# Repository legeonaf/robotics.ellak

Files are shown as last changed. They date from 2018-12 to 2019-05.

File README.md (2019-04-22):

# iHome
Συμμετοχή στο διαγωνισμό ρομποτικής της ellak σχολικού έτους 2018 - 19

**Γεωργία Λέων**  
2ο Γυμνάσιο Ναυπλίου

- [Τί είναι το Έξυπνο σπίτι](smarthome.md)
- [Εξαρτήματα - Τιμές](Εξαρτήματα/README.md)
- [Η Κατασκευή](Κατασκευή/README.md)
- [Ο Προγραμματισμός](Προγραμματισμός/README.md)

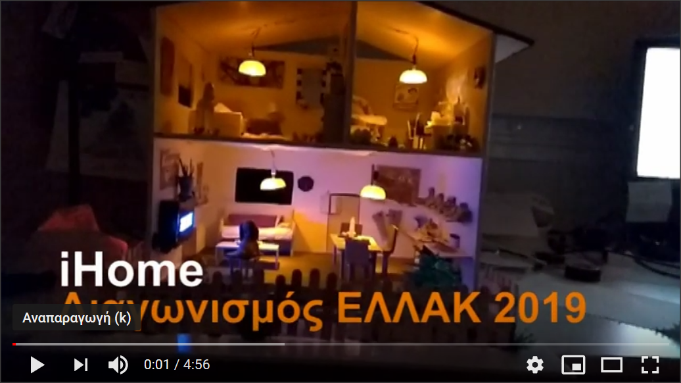
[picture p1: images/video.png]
(https://www.youtube.com/watch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)


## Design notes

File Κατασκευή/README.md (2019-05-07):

# Η κατασκευή

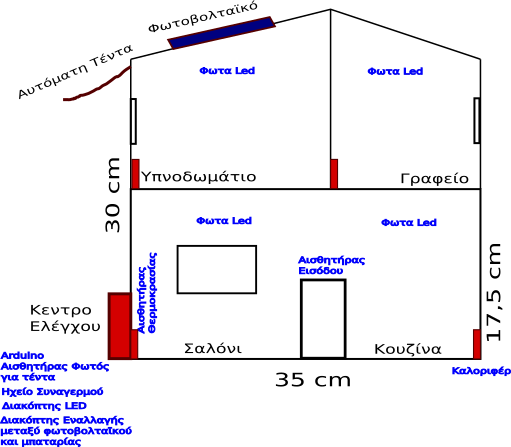
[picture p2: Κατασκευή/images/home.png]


## Συλλογή υλικών

Υλικά:
- Ξυλεία κόντρα πλακέ πάχους 0,5cm
- Ξυλόκολλα
- Ράβδοι κόλλας σιλικόνης, 4-5 ράβδοι
- Χρώματα και βερνίκια ξύλου της επιλογής μας
- Καρφιά και βίδες
- Στόκος ξύλου
- Μικροί μεντεσέδες, 2
- Καλώδια
- Μακετόχαρτο, 45cm*45cm
- Ξυλάκια παγωτού
- Ύφασμα

Για προαιρετικές διακοσμήσεις για το σπίτι και τον κήπο:
- Ξύλα Balsa,ύφασμα, χαρτί, βίδες (για έπιπλα)
- Πράσινο χαρτί γκοφρέ (για γρασίδι)
- Ακρυλικά χρώματα (για το μονοπάτι του κήπου)
- Έτοιμες φιγούρες, φυτά και μινιατούρες επίπλων/πραγμάτων
- Χάρτινα ποτήρια με σχέδια (για πίνακες)

Εργαλεία:
- Χάρακας
- Μέτρο
- Γυαλόχαρτα
- Σφυρί
- Τρυπανάκι
- Kατσαβίδι
- Μολύβι
- Πριόνι
- Χαρτοταινία
- Πιστόλι σιλικόνης

## Επεξεργασία ξυλείας

### Κοπή ξύλων
Μετράμε, σχεδιάζουμε και κόβουμε με το πριόνι τα ξύλα κόντρα πλακέ σε οκτώ παραλληλόγραμμα όπως φαίνοτναι στο σχήμα.
(Π):
- Π1 (πάτωμα κάτω) 35cm*25cm
- Π2 (πάτωμα πάνω) 35cm*25cm
- Π3 (τοίχος δεξιά) 30cm*25cm
- Π4 (τοίχος αριστερά) 30cm*25cm
- Π5 (τοίχος μέση) 17cm*26cm
- Π6 (σκεπή δεξιά) 20,5cm*25cm
- Π7 (σκεπή αριστερά) 26cm*25cm
- Π8 (τοίχος πίσω) 36cm*31cm

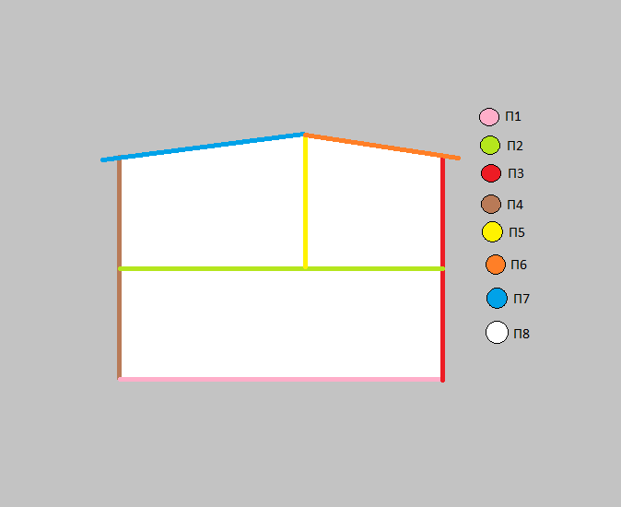
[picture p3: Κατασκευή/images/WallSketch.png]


### Κοπή παραθύρων
Για τα δύο πλαίνα παράθυρα παίρνουμε τα Π3 και Π4 και κόβουμε δύο παραλληλόγραμμες τρύπες για παράθυρα διαστάσεων
8cm(πλάτος)x6cm(ύψος) σε ύψος 21cm και με απόσταση απο τα άκρα 8cm απο την αριστερή άκρη του ξύλου και 9cm απο την δεξιά.
Για το πίσω παράθυρο παίρνουμε το Π8 και κόβουμε ένα παραλληλόγραμμο παράθυρο διαστάσεων 9cm(πλάτος)x5cm(ύψος) σε ύψος 8cm και με απόσταση απο τα άκρα 5,5cm απο την αριστερή άκρη και 21,5cm απο την δεξιά. Για την πόρτα παίρνουμε το ίδιο ξύλο και κάνουμε μια παραλληλόγραμμη τρύπα διαστάσεων 10cm(ύψος)x5cm(πλάτος) με απόσταση απο τα άκρα 20cm απο  την αριστερή άκρη και 11cm απο την δεξιά.

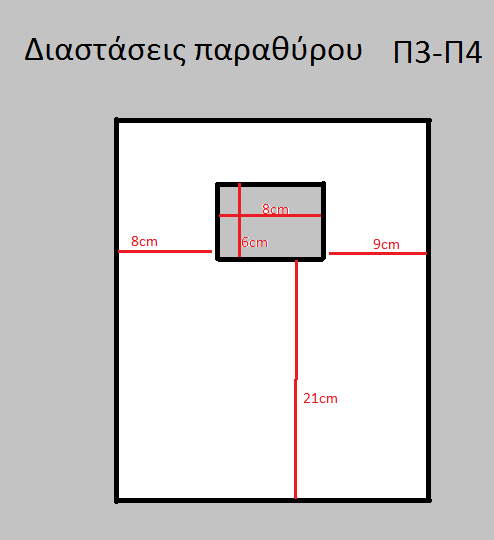
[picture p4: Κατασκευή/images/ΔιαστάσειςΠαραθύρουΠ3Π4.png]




### Στοκάρισμα παραθύρων και πόρτας
Για το στοκάρισμα χρησιμοποιούμε τον στόκο ξύλου και αλείφουμε τις εσωτερικές άκρες των παραθύρων και της πόρτας(κυρίως στος γωνίες) οσο χρειάζεται μεχρι να καλυφθούν τυχών εσοχές και γρατζουνιές που προκλήθηκαν κατα την κοπή. Αφόυ στεγνώσουν τρίβουμε όλα τα ξύλα με το γυαλόχαρτο στις άκρες και στην επιφάνεια καθώς και εκεί που στοκάραμε.



           

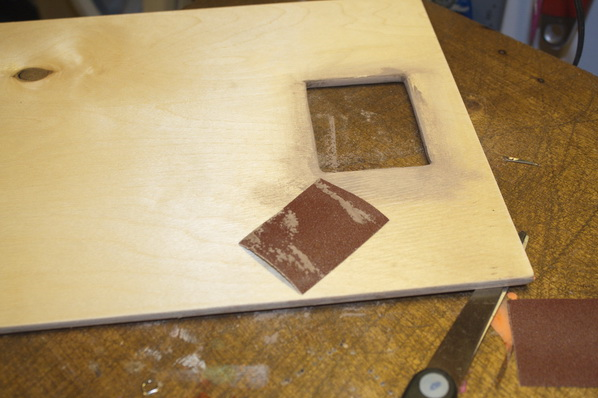
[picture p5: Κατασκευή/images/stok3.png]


## Συναρμολόγηση κομματιών
Για την συναρμολόγηση τρυπάμε τα ξύλα με το τρυπανάκι εκεί που θα βάλουμε τα καρφιά, τα κολλάμε και τα καρφώνουμε σύμφωνα με το σχήμα.



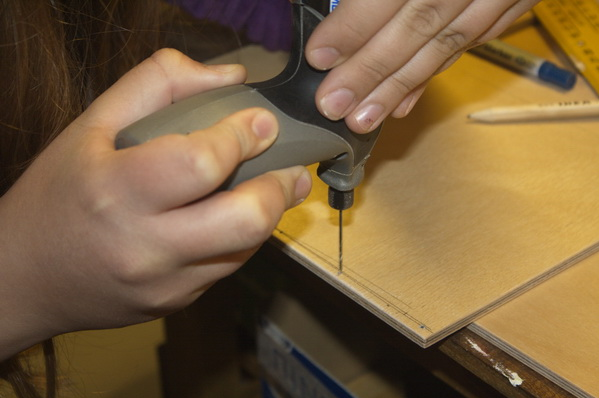
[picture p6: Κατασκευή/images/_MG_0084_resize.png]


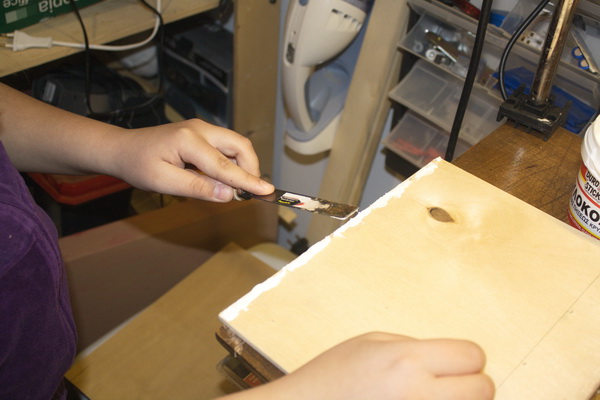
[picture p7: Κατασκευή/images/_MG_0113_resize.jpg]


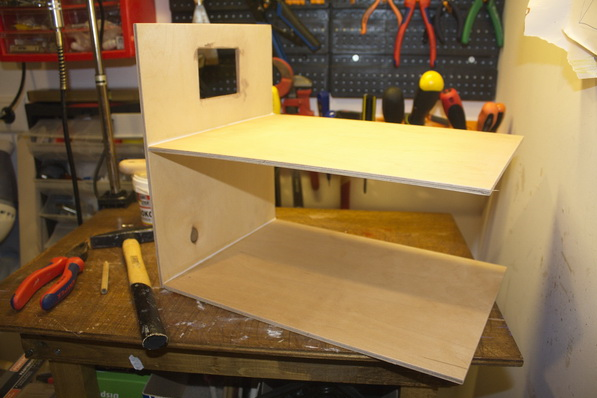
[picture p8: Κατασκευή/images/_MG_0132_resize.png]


## Βάψιμο
Σε αυτό το στάδιο βερνικώνουμε τα πατώματα και αφού στεγνώσουν βάφουμε τους εξωτερικούς και τους εσωτερικούς τοίχους του σπιτιού με χρώματα της επιλογής μας. Χρησιμοποιούμε χαρτοταινία για να μην λερώσουμε το πάτωμα.

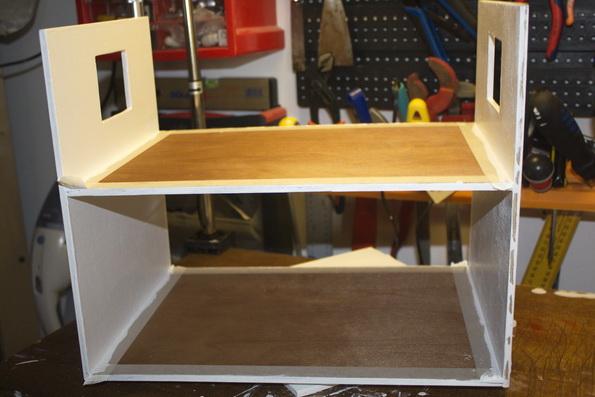
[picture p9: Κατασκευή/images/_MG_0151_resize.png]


## Η κατασκευή της πόρτας
Για την πόρτα θα χρειαστούμε ένα ορθογώνιο ελάχιστα μικρότερο απο την τρύπα στον τοίχο, 9,8cm(ύψος)x4,8cm(πλάτος),για να μπορεί να ανοίγει με τον συναγερμό τοποθετημένο. Βάφουμε την πόρτα με χρώμα της αρεσκείας μας και σε ύψος 5cm
βιδώνουμε μία μικρή βίδα για χερούλι (να μην βγεί απο την άλλη μεριά). Έπειτα με κοντές βίδες βιδώνουμε τoυς μεντεσέδες στην πόρτα και μετά στον τοίχο.

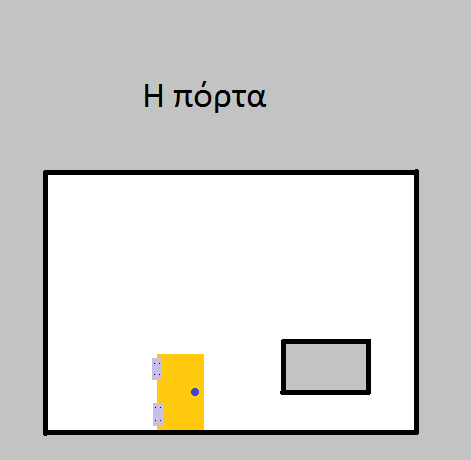
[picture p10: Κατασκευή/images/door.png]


## Η αυλή
Την αυλή την στήνουμε πάνω σε ένα κομμάτι μακετόχαρτο (Εικ.1). Η κατασκευή των φραχτών και της πόρτας γίνεται όπως υποδεικνύει το σκίτσο (Εικ.2+Εικ.3) και με διαστάσεις 11cm, 15cm και 7cm (Εικ.4). Έπειτα κολλάμε τους φράχτες (όχι την πόρτα) στο μακετόχαρτο με κόλλα σιλικόνης (εφόσον θέλετε να διακοσμήσετε τον κήπο κολλήστε και ζωγραφίστε το δάπεδό του πρίν την τοποθέτηση των φραχτών).

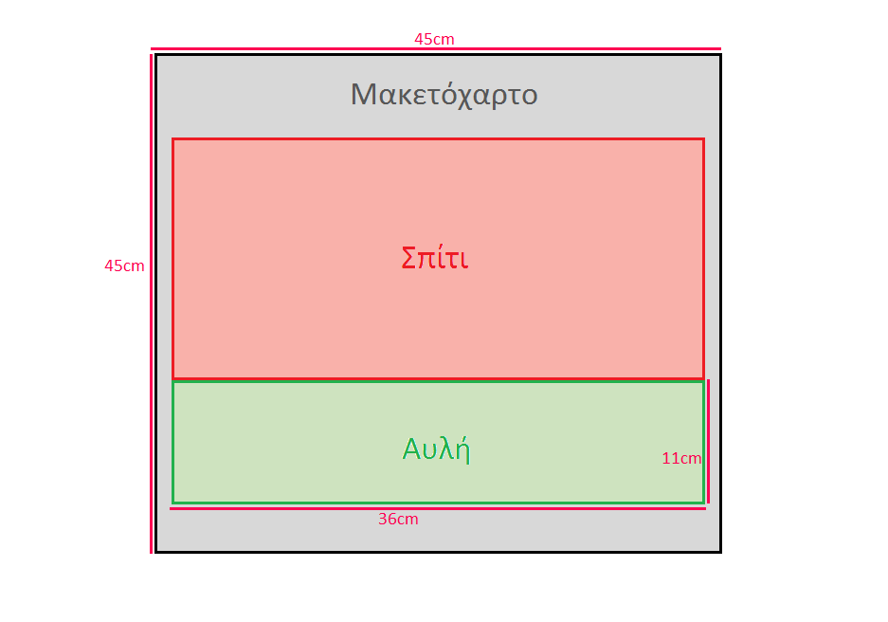
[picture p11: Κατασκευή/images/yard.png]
    
Εικ 1

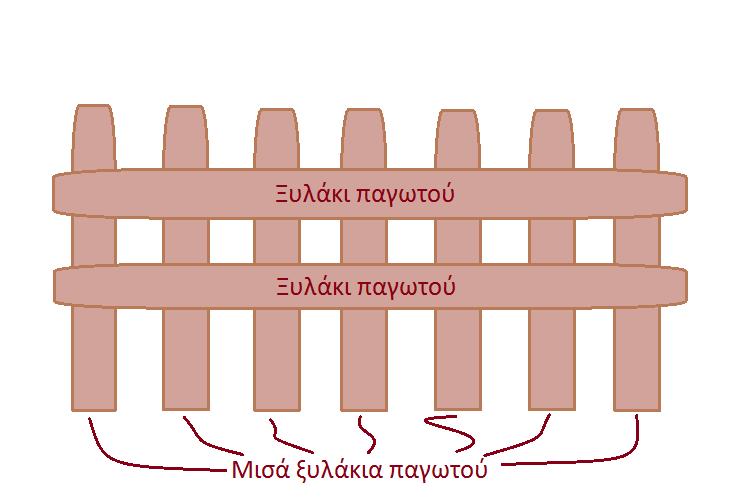
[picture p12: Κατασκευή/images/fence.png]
     
Εικ 2

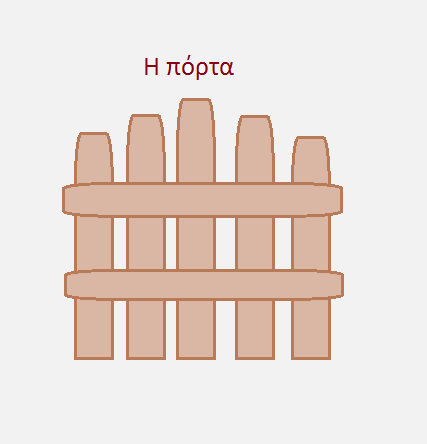
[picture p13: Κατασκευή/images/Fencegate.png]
   
Εικ 3

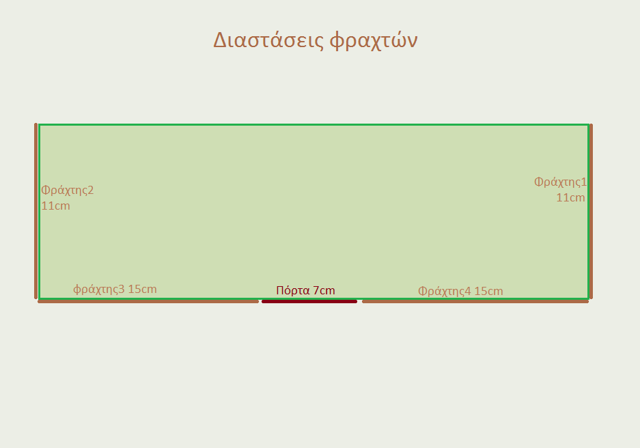
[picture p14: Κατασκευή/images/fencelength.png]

Εικ 4

## Η τέντα
Η τέντα αποτελείται απο τον σκελετό, τρία ξυλάκια για σουβλάκι (τα δύο 9cm και το μεσαίο 11cm) κολλημένα σε σχήμα Π με σιλικόνη, και το πανί (11cm x 11cm) του οποίου η μία άκρη είναι κολλημένη στο πάνω μέρος του παραθύρου και η απένατι άκρη στο μεσαίο ξυλάκι του σκελετού. Τα ξυλάκια στηρίζονται στον τοίχο απο δύο κλειστά γατζάκια που κλείνουν γύρω απο δύο μικρούς δακτυλίους που θα βιδώσουμε (ο ένας 1cm αριστερότερα απο το παράθυρο και ο άλλος 1cm δεξιότερα, και οι δύο σε ευθεία με την βάση του παραθύρου) ωστε να μπορεί να ανοιγοκλείνει.



## Καλωδίωση και τοποθέτηση εξαρτημάτων
###### Τώρα η μακέτα είναι έτοιμη να καλωδιωθεί:

#### Φώτα
Τα φώτα είναι 4 και τοποθετούνται 2 σε κάθε όροφο. Για τα πάνω φώτα βρίσκουμε την μέση του ταβανιού των δύο δωματίων.
Εκεί θα είναι οι άκρες των καλωδίων. Aρχίζοντας απο εκεί κολλάμε τις άκρες τους με σιλικόνη κάθετα και συνεχίζουμε να κολλάμε το καλώδιο ακολουθόντας κατεύθυνση προς το Arduino (D3-D4, GND).

#### Οθόνη
Η οθόνη θα τοποθετηθεί στον τοίχο Π4 δίπλα στο καλοριφέρ. Φτιάχνουμε ένα πλαίσιο απο μακετόχαρτο και την κολλάμε μέσα. Ανοίγουμε μια τρύπα στον τοίχο απο όπου θα βγαίνουν τα καλώδια της. Έπειτα την κολλάμε στον τοίχο με σιλικόνη. Τα καλώδια θα βγούν απο τον τοίχο και θα συνδεθούν στο Arduino (A4-A5, GND, 5v).

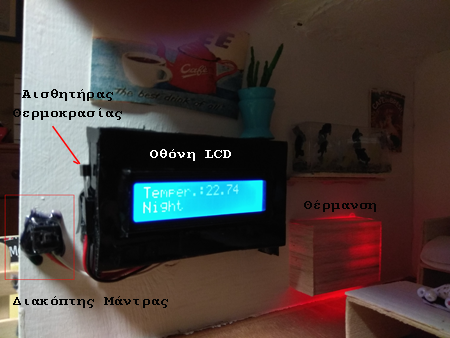
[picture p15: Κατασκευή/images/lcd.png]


Η οθόνη εμφανίζει συνεχώς την θερμοκρασία του χώρου στην πρώτη γραμμή ενώ στην δεύτερη ανάλογα με την ένδειξη του αισθητήρα φωτός εμφανίζει Day ή Night.

#### Θερμανση
Το καλοριφέρ είναι φτιαγμένο απο ένα λεπτό ξύλινο παραλληλόγραμμο ξύλο balsa χωρίς πάτο. Μέσα κολλάμε ένα κόκκινο LED φωτάκι μαζί με μια αντίσταση 220Ω σε σειρά με τον θερικό πόλο. Το καλοριφέρ θα τοποθετηθεί στον τοίχο Π4.  Κάνουμε μία τρύπα στον τοίχο, περνάμε απο μέσα τα καλώδια, τα συνδέουμε στο Arduino και  κολλάμε το καλοριφέρ με σιλικόνη στο Π4 (D13, GND). Μέσα από τον κώδικα έχει γίνει ρύθμιση να ανάβει το led (δηλαδή η θέρμανση) όταν η θερμοκρασία πέσει κάτω από 23 βαθμούς. Παράλληλα ακόμη και αν είναι μέρα η τέντα σηκώνεται ώστε να βοηθήσει ο ήλιος στη θέρμανση του σπιτιού.

#### Συναγερμός
Ο  συναγερμός θα τοποθετηθεί στην πόρτα όπως υποδεικνύει το σκίτσο με τα καλώδια να κατευθύνονται προς το Arduino (D9, GND).

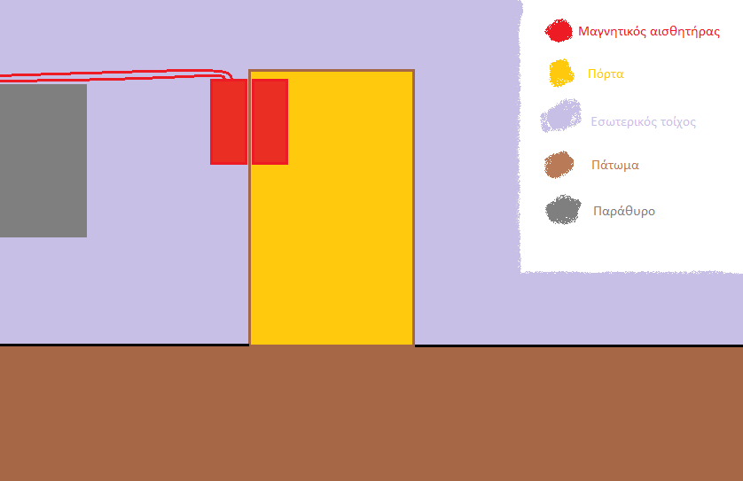
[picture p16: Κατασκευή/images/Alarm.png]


#### Κινητήρας τέντας
O κινητήρας της τέντας θα κολληθεί πλάγια στην αριστερή πλευρά του παραθύρου με τον βραχείωνα κολλημένο στο αριστερό ξυλάκι του σκελετού της. Τα καλώδια ακολουθούν κατεύθυνση προς το Arduino (D12, GND).


#### Κινητήρας αυλόπορτας
Ο κινητήρας της αυλόπορτας θα κολληθεί σε όρθια θέση στην αριστερή πλευρά του ανοίγματος για την πόρτα με τα καλώδια να κοιτάνε προς αυτό. Παίρνουμε τον βραχείωνα του κινητήρα και κολλάμε πάνω την πόρτα που έχουμε ετοιμάσει απο πρίν, προσέχοντας να υπάρχει περιθώριο ανάμεσσα στο δάπεδο και την πόρτα για να μπορεί να ανοιγοκλείνει. Έπειτα κάνουμε μία τρύπα στο μακετόχαρτο εκεί που είναι τα καλώδια του κινητήρα και τα περνάμε απο κάτω, για να μην φαίνονται, ακολουθώντας κατεύθυνση προς το Arduino (D11, GND, 5V).
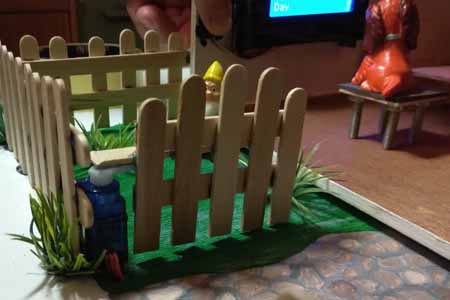
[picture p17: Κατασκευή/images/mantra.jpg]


#### Διακόπτης λειτουργίας & Διακόπτης φωτών
Ο διακόπτης λειτουργίας είναι τριών επιλογών. Στην θέση 1 τροφοδοτεί το Arduino απο μπαταρία 9 volt, στην θέση 2 τροφοδοτείται το Arduino απο τα φωτοβολταϊκά και στην θέση 0 είναι σβηστό.

Ο διακόπτης τοποθετείται στην θήκη του Arduino απο την εξωτερική πλευρά (D5, GND)


#### Διακόπτης αυλόπορτας
Ο διακόπτης της εξώπορτας θα τοποθετηθεί στο εσωτερικό του σπιτιού δίπλα στην τηλεόραση ωστε τα καλώδιά του να βγούν απο την τρύπα στον τοίχο και να ακολουθήσουν πορεία προς το Arduino (D6, GND).

#### Ηχείο
Το ηχείο τοποθετείται στο κουτί του Arduino (D8, GND)

#### Φωτοβολταικά
Τα φωτοβολταικά παράγουν 6v τάσης και είναι συνδεδεμένα παράλληλα προκειμένου να δίνουν επαρκή ένταση σε όλα τα εξαρτήματα του σπιτιού .

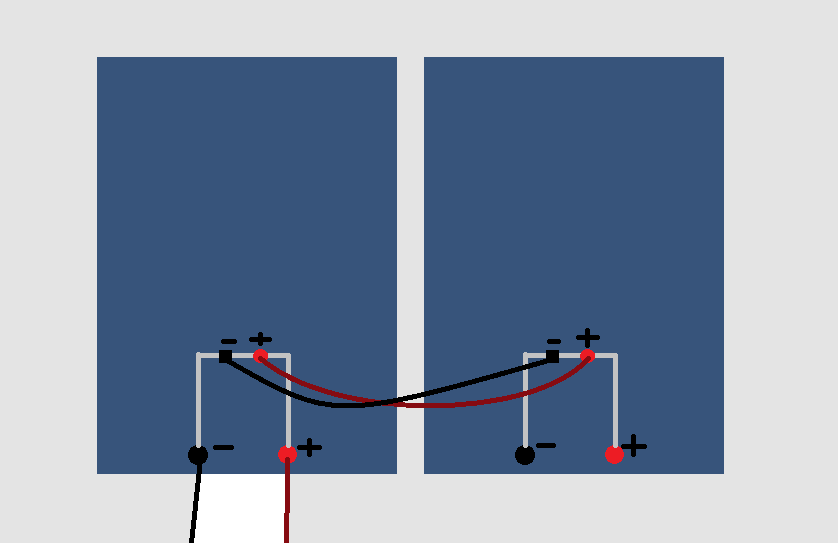
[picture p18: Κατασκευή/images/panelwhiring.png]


#### Αισθητήρας θερμοκρασίας
Ο αισθητήρας θερμοκρασίας τοποθετείται πάνω στο πλαίσιο της οθόνης με τα καλώδια να περνάνε μέσα απο το πλαίσιο, να βγαίνουν απο την τρύπα στον τοίχο και ναι κατευθύνονται προς το Arduino (Α1, GND, 5v)

#### Φωτοαντίσταση
Η φωτοαντίσταση τοποθετείται πάνω στο κουτί του Arduino κάτω απο τον κινητήρα της τέντας και συνδέεται με το Arduino (A2, GND, )

[Αρχική Σελίδα έργου](https://github.com/legeonaf/robotics.ellak)

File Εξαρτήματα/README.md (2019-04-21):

# Τα εξαρτήματα, τιμές και η χρήση τους

## Εξαρτήματα - Τιμές
A/A   | Περιγραφή   | Ποσότητα  | Τιμή / Τεμ. € | Σύνολο €
------| ------------|-----------|---------------|----------
1 | [LM35DZ LM35 TO-92 NSC TEMPERATURE SENSOR IC](https://www.ebay.com/itm/1PCS-LM35DZ-LM35-TO-92-NSC-TEMPERATURE-SENSOR-IC-Inductor-NEW/232397948189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) | 1 | 0.84 | 0.84
2 | [Αισθητήρας φωτός](https://www.ebay.com/itm/1-2-5-10-PCS-LM393-Optical-Photosensitive-Light-Sensor-Module-Arduino-Shield/302095762590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) | 1 | 0.65 | 0.65
3 | Αισθητήρας πόρτας (μαγνητική επαφή διακόπτης)| 1 | 1 | 1
4 | [Led για τα φώτα λευκά ή κίτρινα](https://grobotronics.com/led-diffused-5mm-white.html) | 4 | 0.2 | 0.8
5 | [Led για τα καλοριφέρ](https://grobotronics.com/led-diffused-5mm-elrd.html)  | 1 | 0.1 | 0.1
6 | [Κινητήρας σέρβο για την τέντα](https://grobotronics.com/servo-micro-1.5kg.cm-plastic-gears-feetech-fs90.html) | 1 | 4.90 | 4.90
7 | [Κινητήρας σέρβο για την μάντρα](https://grobotronics.com/servo-micro-1.5kg.cm-plastic-gears-feetech-fs90.html) | 1 | 4.90 | 4.90
8 | [Solar Panel 2W 136x110mm](https://grobotronics.com/solar-panel-2w-136x110mm.html)  | 2  |  5.90 |  11.80  |        
9 | [Ηχείο buzzer](https://grobotronics.com/buzzer-2-5v-30ma.html) | 1 | 0.65 | 0.65
10| [I2C 1602 Blue Backlight LCD Display Screen Module For Arduino](https://www.ebay.com/itm/IIC-I2C-1602-Blue-Backlight-LCD-Display-Module-For-Arduino/382822425595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)  | 1  | 3 | 3.53
11| [Arduino Nano compatible](https://grobotronics.com/nano-ft232-atmega328p-compatible-for-arduino-nano.html) | 1  | 9  |  9
12  | [Project Box 135x135x60mm](https://grobotronics.com/project-box-135x135x60mm-grey.html)   | 1   | 6.4  |  6.4
13| Αντιστάσεις 1/4 W 220 Ω και 10ΚΩ  | 10  | 0.01  |  0.1
14| Κόντρα Πλακέ πάχους 6mm  |   |   | 7  
15| Ξύλο Μπάλσα  |   |   | 4
16| Μακετόχαρτο  | 1  |   | 1
17| Ξυλάκια Παγωτού για φράχτη | 1 πακ.  | 1.5  |  1.5
18| Διάφορα μικρα υλικά από παιχνίδια κλπ  |   |   |  
  | **Σύνολο**  | | |  58€

#### Το ολοκληρωμένο κύκλωμα του σπιτιού

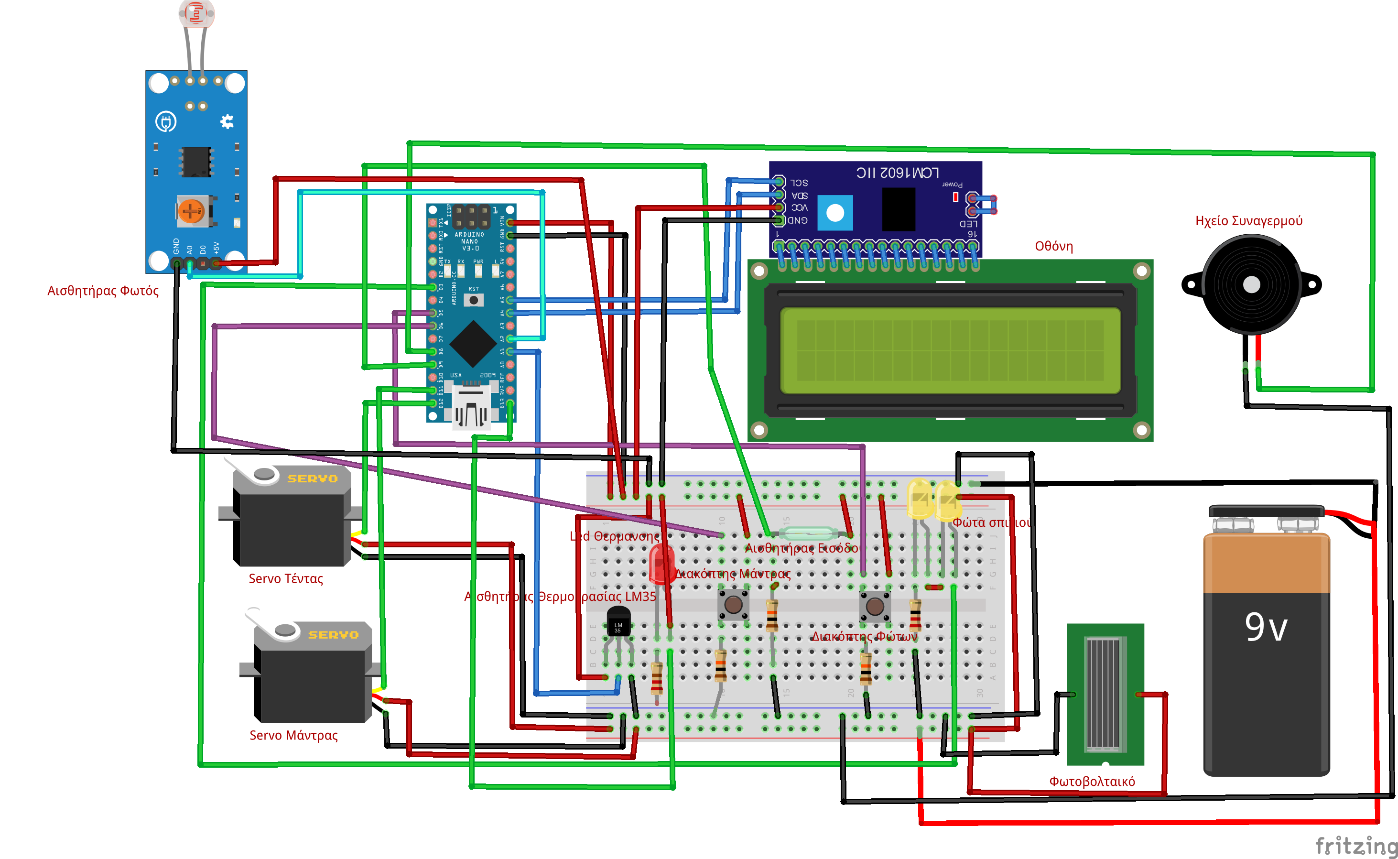
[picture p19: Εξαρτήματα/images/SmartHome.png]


### Arduino nano
Ο μικροελεγκτής Arduino αποτελείται από ένα μικροεπεξεργαστή και ένα περιβάλλον ανάπτυξης προγραμμάτων. Το Arduino μπορεί να δέχεται δεδομένα όπως για παράδειγμα από ενεργοποίηση αισθητήρων και στη συνέχεια να ενεργοποιεί εξόδους.

Χρησιμοποιείται από εκπαιδευτικούς και σπουδαστές για την κατασκευή χαμηλού κόστους επιστημονικών συσκευών, από χομπίστες, καλλιτέχνες κλπ. Τα βασικά σημεία που το κάνουν να ξεχωρίζει είναι:
- Χαμηλό κόστος. Είναι ίσως από τα χαμηλότερα σε κόστος ηλεκτρονικά κυκλώματα.
- Ανεξάρτητο πλατφόρμας. Μπορεί να χρησιμοποιηθεί τόσο σε Windows, Linux και Mac
- Απλό και εύχρηστο περιβάλλον ανάπτυξης. Χρησιμοποιεί την γλώσσα προγραμματισμού Wiring (έκδοση της C), αλλά έχουν αναπτυχθεί περιβάλλοντα για μικρότερες ηλικίες στο scratch (π.χ. Scratch for Arduino S4A, scratchX, mblock κλπ)
- Ανοιχτού κώδικα. Όλοι οι κώδικες και τα σχέδια των ηλεκτρονικών κυκλωμάτων είναι ελεύθερα για χρήση.

Στην συγκεκριμένη εργασία χρησιμοπούμε το Arduino nano και το προγραμματίζουμε με το mblock.
Το Arduino Nano
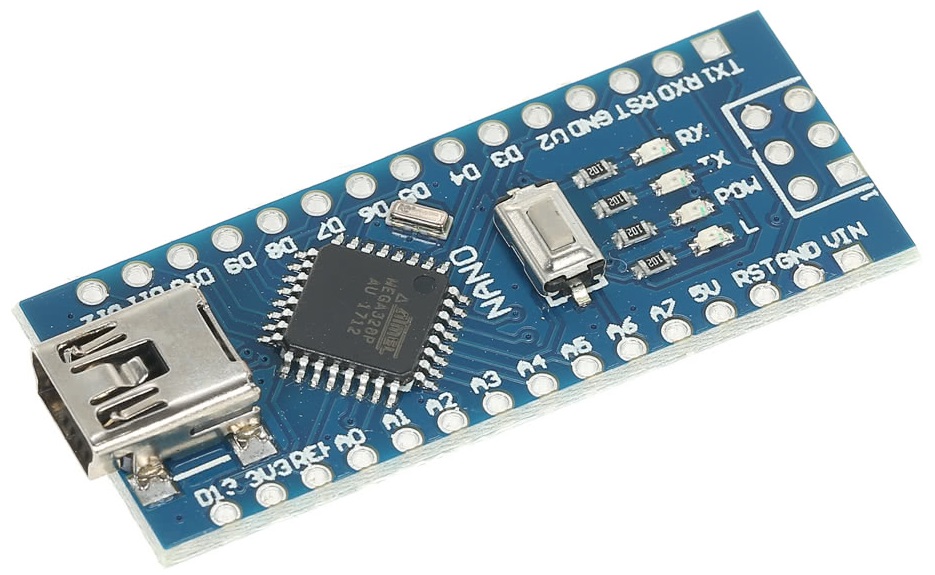
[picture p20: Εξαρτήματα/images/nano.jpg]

Αποτελείται από ψηφιακές εισόδους-εξόδος και αναλογικές εισόδους όπου και συνδέουμε όλα τα εξαρτήματα με τα οποία θέλουμε να επικοινωνεί.

### Αισθητήρας θερμοκρασίας LM35 Έλεγχος Θερμοκρασίας

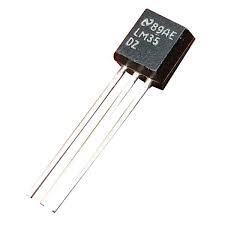
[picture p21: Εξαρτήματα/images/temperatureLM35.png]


- Λειτουργεί με τάση εισόδου από 4 έως 30 Volt
- Μετράει θερμοκρασίες από -55 έως 150ο C
- Κοιτάζοντας την μπροστινή πλευρά του LM35 (επίπεδη πλευρά), ο αριστερός ακροδέκτης είναι ο ακροδέκτης της τροφοδοσίας και ο δεξιός ακροδέκτης είναι ο ακροδέκτης της γείωσης. Ο μεσαίος συνδέεται με  ένα από τα pin αναλογικής εισόδου.
- Για κάθε ένα βαθμό Κελσίου (C) αντιστοιχούν 10 mV.

Σύνδεση με το Arduino


### Αισθητήρας φωτός και η Τέντα

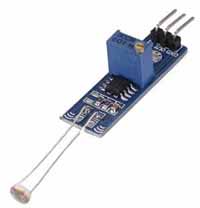
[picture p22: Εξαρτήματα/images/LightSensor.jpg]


Η φωτοαντίσταση είναι μια μεταβλητή αντίσταση η τιμή της οποίας αλλάζει ανάλογα με το φως που πέφτει πάνω σε αυτή. Τη φωτοαντίσταση τη συναντάμε σε κυκλώματα τα οποία θέλουν με κάποιο τρόπο να αναγνωρίσουν αν το περιβάλλον είναι φωτεινό ή σκοτεινό.

Σύνδεση με το Arduino
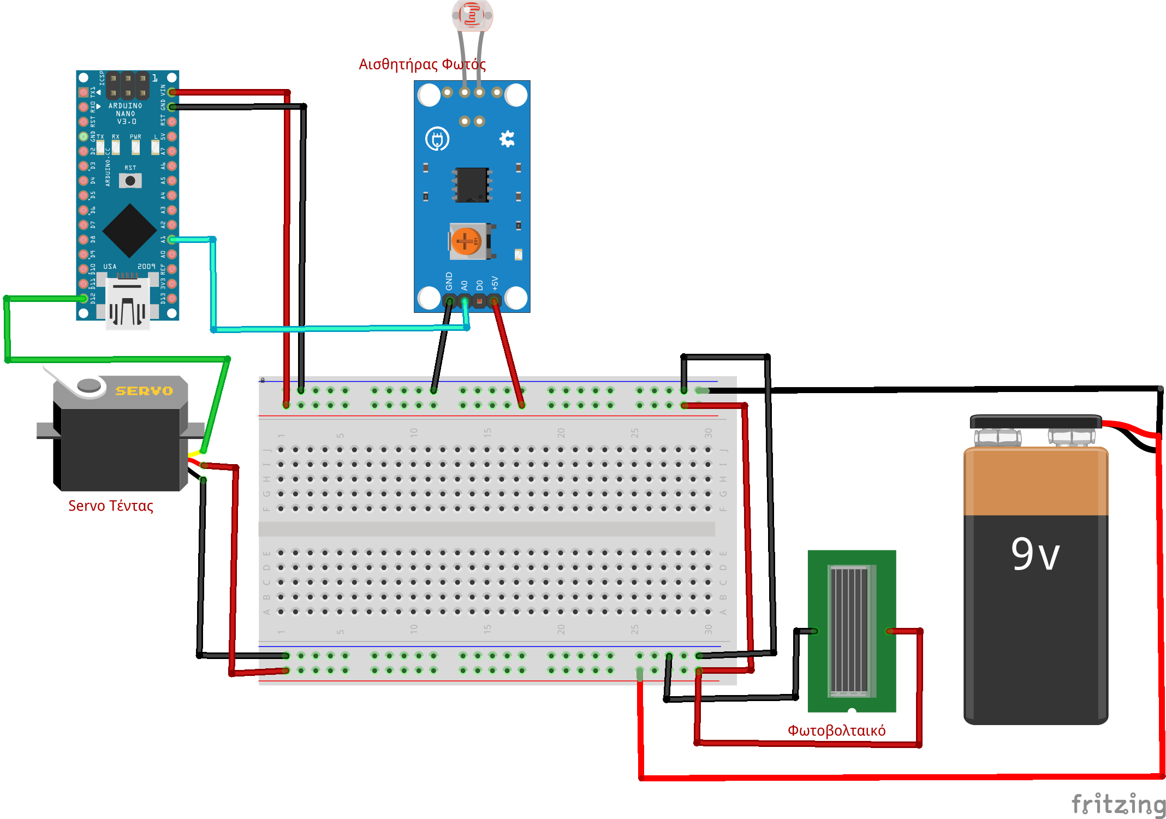
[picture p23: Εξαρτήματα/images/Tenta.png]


### Κινητήρας σέρβο

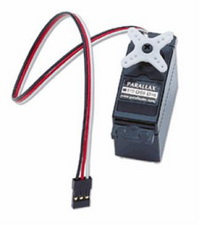
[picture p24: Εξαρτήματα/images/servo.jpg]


Οι κινητήρες servo είναι μικρές συσκευές που έχουν έναν εξωτερικό άξονα. Αυτός ο άξονας μπορεί να μετακινηθεί σε διάφορες θέσεις αν αποσταλεί στον servo ένα κωδικοποιημένο σήμα. Όσο υπάρχει αυτό το σήμα στην γραμμή εισόδου του Servo τόσο αυτός θα διατηρεί τον άξονα του σε μια συγκεκριμένη θέση. Όταν αλλάζει το σήμα προκαλεί στον servο να μεταβάλει την γωνία του άξονα. Η τάση που απαιτεί για την λειτουργία του είναι 5-6 Volt DC. Ο άξονας του έχει μπορεί να μετακινηθεί από την θέση 0ο στη θέση 180ο σε 1.5 second. Αυτό ορίζεται και ως η ταχύτητα του κινητήρα. Ζυγίζει περίπου 45gr και έχει ροπή στρέψης 3.40 kg-cm.

Στο έξυπνο σπίτι χρησιμοποιούμε 2 κινητήρες servo έναν για να
ανοιγοκλείνει την τέντα ανάλογα με το φως και την θερμοκρασία και τον δεύτερο για να ανοιγοκλείνει την πόρτα της αυλής όταν πατηθεί ο διακόπτης μέσα στο σπίτι.

### Mαγνητική επαφή

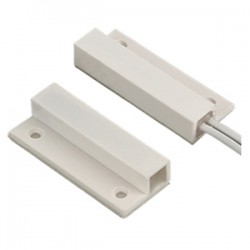
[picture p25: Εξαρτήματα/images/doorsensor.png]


Η λειτουργία των αισθητήρων μαγνητικής επαφής βασίζεται σε ένα αισθητήρα και ένα μαγνήτη. Ο αισθητήρας τοποθετείται στο κάσωµα της πόρτας ή του παραθύρου, ενώ η μαγνητική επαφή τοποθετείται πάνω στην πόρτα ή πάνω στο παράθυρο . Αυτό δημιουργεί ένα κύκλωμα το οποίο, όταν παραβιαστεί( με το άνοιγμα μιας πόρτας η ενός παραθύρου, τότε στέλνει σήμα στη κεντρική μονάδα συναγερμού, η οποία και αντιλαμβάνεται τη παραβίαση της εκάστοτε ζώνης και ενεργοποιεί το συναγερμό.

Σύνδεση με το Arduino


### Led φώτα



Μια δίοδος εκπομπής φωτός (light emitting diode,LED) είναι στην ουσία μια ένωση pn που έχει κατασκευαστεί από ένα ημιαγωγό άμεσου ενεργειακού χάσματος και στην οποία η επανασύνδεση των ζευγών ηλεκτρονίων έχει ως αποτέλεσμα την εκπομπή φωτονίων.

Σύνδεση με το Arduino


### Φωτοβολταϊκά



Τα φωτοβολταϊκά ανήκουν στη κατηγορία των Ανανεώσιμων Πηγών Ενέργειας. Η λειτουργία του φωτοβολταϊκού συστήματος στηρίζετε στις βασικές ιδιότητες των ημιαγωγών υλικών σε ατομικό επίπεδο. Όταν το φως προσπίπτει σε μια επιφάνεια είτε ανακλάται, είτε την διαπερνά (διαπερατότητα) είτε απορροφάται από το υλικό της επιφάνειας. Η απορρόφηση του φωτός ουσιαστικά σημαίνει την μετατροπή του σε μια άλλη μορφή ενέργειας η οποία συνήθως είναι η θερμότητα.
Παρόλα αυτά όμως υπάρχουν κάποια υλικά τα οποία έχουν την ιδιότητα να μετατρέπουν την ενέργεια των προσπιπτοντων φωτονίων σε ηλεκτρική ενέργεια. Αυτά τα υλικά είναι οι ημιαγωγοί.

### Ηχείο Buzzer



Το ηχείο Buzzer είναι παθητικό επειδή δεν διαθέτει κανένα σύστημα ώστε να παράγει ήχο ή ηχώ από μόνο του. Είναι απαραίτητο για το Buzzer ένας μικροελεγκτής, όπως ένα Arduino για να παράγει ήχο. Επειδή η συσκευή είναι παθητική, λειτουργεί περισσότερο σαν ένα μικρό ηχείο παρά ένα βομβητή.  Τέτοια ηχεία συναντάμε σε υπολογιστές, ξυπνητήρια, σε συστήματα συναγερμού κ.α.

Σύνδεση με το Arduino


### Διακόπτης



Οι διακόπτες έχουν σημεία με τα οποία συνδέονται με το κύκλωμα τα οποία ονομάζονται ακροδέκτες. Κάθε διακόπτης έχει δύο καταστάσεις, την κατάσταση που είναι κλειστός και την κατάσταση που είναι ανοιχτός. Όταν ένας διακόπτης είναι ανοιχτός δεν επιτρέπει τη διέλευση ηλεκτρικού ρεύματος μεταξύ των ακροδεκτών του, ενώ όταν είναι κλειστός επιτρέπει τη διέλευση ηλεκτρικού ρεύματος μεταξύ των ακροδεκτών του.

Σύνδεση με το arduino


Οι διακόπτες συνδέονται πάντα με μία μεγάλη αντίσταση της τάξεως των 10ΚΩ στην πλευρά της γείωσης.

[Αρχική Σελίδα έργου](https://github.com/legeonaf/robotics.ellak)

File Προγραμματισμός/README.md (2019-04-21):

# Ο προγραμματισμός

## Ψηφιακά Pins του Arduino που χρησιμοποιήθηκαν
A/A | Εξάρτημα | Digital Pin
------| ------------|-----------
1 | Φώτα ορόφου  | D3
2 | Φώτα εισογείου  |  D4
3 | Διακόπτης φώτων  |  D5
4 | Διακόπτης Μάντρας  |  D6
5 | Ηχείο  |  D8
6 | Μαγνητική Επαφή Πόρτας |  D9
7 | Servo κινητήρας Μάντρας  |  D11
8 | Servo κινητήρας Τέντας  |  D12
9 | Led Θέρμανσης  |  D13

## Αναλογικά Pins που χρησιμοποιήθηκαν

A/A | Εξάρτημα | Analog Pin
------| ------------|-----------
1 | Αισθητήρας θερμοκρασίας LM 35 | Α1
2 | Αισθητήρας Φωτός | Α2
3 | Οθόνη LCD 16x2  |  A4 - A5

## Λειτουργίες του έξυπνου σπιτιού
Οι λειτουργίες που προγραμματιστηκαν  είναι οι εξής:
- Άνοιγμα/κλείσιμο των εσωτερικών φώτων του σπιτιού
- Άνοιγμα/κλείσιμο της τέντας αυτόματα ανιχνεύοντας το φώς που χτυπάει το σπίτι και βάσει της θερμοκρασίας του σπιτιού
- Άνοιγμα/κλείσιμο της αυλόπορτας με το πάτημα ενός κουμπιού
- Άνοιγμα/κλείσιμο του καλοριφέρ του σπιτιού βάσει της θερμοκρασίας του
- Προβολή στην οθόνη της θερμοκρασίας του σπιτιού και του φωτός που το χτυπάει
- Ενεργοποίηση συναγερμού με το άνοιγμα της πόρτας

## Ο προγραμματισμός και ο κώδικας
Ο προγραμματισμός της μακέτας έγινε με το mBlock, σε περιβάλλον scratch.

###  Δημιουργία μεταβλητών
Το πρώτο βήμα στον προγραμματισμό είναι η δημιουργία των μεταβλητών που θα χρησιμοποιήσουμε.



Γράφουμε το pin στο οποίο συνδέεται το εξάρτημα του οποίου την μεταβλητή δημιουργούμε και το όνομα του εξαρτήματος (το όνομα της μεταβλητής δεν έχει σημασία αρκεί να μπορούμε να ξεχωρήσουμε σε ποιό εξάρτημα αντιστοιχεί). Αφού φτιάξουμε τις μεταβλητές για όλα τα pins μετά φτιάχνουμε τις βοηθητικές, *ΘερμοκρασίαΒάσης*, *Temp*, *Voltage*, οι οποίες δεν αντιστοιχούν σε κάποιο pin και απλά παίρνουν μια τιμή για να βοηθήσουν στον κώδικα.

### Ορισμός μεταβλητών
Τώρα αφού έχουμε δημιουργήσει τις μεταβλητές είναι η ώρα να τους δώσουμε μία τιμή ή να τις ορίσουμε σε ένα pin.



### Η οθόνη LCD
Για να δουλέψει η οθόνη με το πρόγραμμα Mblock θα πρέπει αρχικά να εγκαταστήσουμε από το μενού Επεκτάσεις --> Διαχείριση Επεκτάσεων
την επέκταση LCD I2C Pack
images

Οι εντολές που αφορούν την οθόνη στην αρχή του προγράμματος είναι οι παρακάτω:



- Η εντολή Set LCD ορίζει τις ιδιότητες της οθόνη που θα χρησιμοποιήσουμε και
- η Clear LCD καθαρίζει την οθόνη.

### Ο διακόπτης της πόρτας
Το πρώτο κομμάτι του κώδικα είναι ο προγραμματισμός του διακόπτη που ανοίγει την αυλόπορτα.



Ορίζουμε την μεταβλητή του διακόπτη να διαβάσει το digital pin 6. Άν ο διακόπτης είναι κλειστός και παιρνάει ρεύμα, άρα είναι Χ>0, τότε ο κινητήρας θα κινηθεί 90 μοίρες αλλιώς θα παραμείνει στις 0.

### Διακόπτης φώτων
Για τον προγραμματισμό του διακόπτη των φώτων θα χρησιμοποιήσουμε την ίδια λογική με τον προηγούμενο διακόπτη μόνο που τώρα θα στείλουμε ή θα κόψουμε το ρεύμα σε δύο pins ταυτόχρονα.



### Μαγνητική επαφή
Για την μαγνητική επαφή ορίζουμε την μεταβλητή της να διαβάσει το pin 9 για input και άμα δεν περνάει ρεύμα, δηλαδή είναι Χ=0, τότε βάζουμε το pin 8, το buzzer, να παίξει ένα τόνο που μοιάζει με συναγερμό.



### Τέντα, και αισθητήρας θερμοκρασίας
Η τέντα και ο αισθητήρας θερμοκρασίας σχετίζονται μεταξύ τους. Πρώτα εξετάζεται η θερμοκρασία και αν αυτή είναι κάτω από 23 βαθμούς τότε η τέντα παραμένει κλειστή προκειμένου ο ήλιος να ζεστάνει γρηγορότερα το σπίτι και επιπρόσθετα ανάβει το καλοριφέρ. Οταν η θερμοκρασία ξεπεράσει τους 23 βαθμούς τότε εξετάζουμε τον αισθητήρα φωτός και ανοίγει την τέντα εφόσον είναι μέρα.

### Το ολοκληρωμένο πρόγραμμα


[Αρχική Σελίδα έργου](https://github.com/legeonaf/robotics.ellak)

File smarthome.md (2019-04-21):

## 1. ΛΕΙΤΟΥΡΓΙΑ ΤΟΥ ΕΞΥΠΝΟΥ ΣΠΙΤΙΟΥ

### 1.1	ΤΙ ΕΙΝΑΙ ΤΟ ΕΞΥΠΝΟ ΣΠΙΤΙ
Έξυπνο σπίτι ονομάζεται ένα κτήριο του οποίου οι περισσότερες λειτουργείες, με την βοήθεια ειδικών χειριστηρίων, γίνονται αυτόματα. Έχει την δυνατότητα να συνδεθεί και να επικοινωνήσει με άλλες έξυπνες συσκευές όπως το κινητό τηλέφωνο, ο ηλεκτρονικός υπολογιστής και άλλα. Οι περισσότερες συσκευές που το αποτελούν συνδέονται με τα χειριστήρια, ώστε, ο κάτοχός τους να μπορεί να τις χειριστεί από απόσταση ενός δωμάτιου ή ενός χιλιομέτρου.

### 1.2	ΟΙ ΑΥΤΟΜΑΤΙΣΜΟΙ  ΤΟΥ ΣΠΙΤΙΟΥ
Ορισμένες από τις λειτουργίες του σπιτιού αυτοματοποιούνται με στόχο να γίνει πιο εύχρηστο, πιο άνετο και πιο γρήγορο. Τα βασικά στοιχεία των αυτοματισμών του κτηρίου είναι:
- Σύστημα ασφαλείας
- Σύστημα παρακολούθησης
- Σύστημα φωτισμού
- Σύστημα ηλεκτρονικών συσκευών
- Σύστημα free cooling, αερισμού, πρόψυξης, προθέρμανσης
- Σύστημα ρολών-τεντών και θυρών
- Σύστημα διανομής δορυφορικού και τηλεοπτικού σήματος
- Σύστημα διανομής εικόνας και ήχου
- Σύστημα κεντρικής διαχείρισης και εποπτείας
- Σύστημα ποτίσματος
- Σύστημα ανίχνευσης πυρκαγιάς και πλημύρας

Ένα έξυπνο σπίτι εκτός από τις λειτουργείες που μπορεί να εκτελέσει έχει την δυνατότητα να επικοινωνεί και με τον ιδιόκτητη, είτε αυτός βρίσκεται εντός του κτηρίου είτε βρίσκεται σε κάποια απομακρυσμένη περιοχή.

## 2. ΙΣΤΟΡΙΚΗ ΕΞΕΛΙΞΗ ΕΞΥΠΝΟΥ ΣΠΙΤΙΟΥ

### 2.1 Ο ΟΡΟΣ ‘’ΕΞΥΠΝΟ ΣΠΙΤΙ‘’
Από την αρχή της ανθρωπότητας, ο άνθρωπος αναζητούσε ένα φυσικό μέρος το οποίο θα τον κρατούσε ασφαλή από διάφορους εξωτερικούς κινδύνους και καιρικά φαινόμενα. Χρησιμοποιώντας υλικά από το περιβάλλον στο οποίο ζούσε κατάφερε να δημιουργήσει το πρώτο σπίτι η αλλιώς καταφύγιο. Με το πέρασμα του χρόνου και την αύξηση της τεχνολογίας, το σπίτι έπαψε να καλύπτει μόνο την ανάγκη της ασφάλειας και άρχισε να αναζητεί και την αίσθηση της άνεσης .Ο ρόλος του σπιτιού στη σύγχρονη εποχή ικανοποιεί τις ανάγκες του ανθρώπου για γρηγορότερη και με όσο το δυνατόν λιγότερο κόπο, κάλυψη των αναγκών του, με τη βοήθεια των ηλεκτρικών συσκευών, η τεχνολογία πλέον έχει εισβάλλει στο οικιακό περιβάλλον σε κάθε πτυχή της καθημερινότητας. Οι ανάγκες όμως του σύγχρονου ατόμου και οι ρυθμοί που επιβάλει η σύγχρονη κοινωνία σε άμεση συνάρτηση με την ανάπτυξη της τεχνολογίας και της επιστήμης της πληροφορικής, οδηγούν τον άνθρωπο στο να προσπαθεί να αυτοματοποιήσει τις λειτουργίες ενός σπιτιού. Κάπως έτσι γεννήθηκε ο όρος “ Έξυπνο σπίτι”.

## 3. ΔΟΜΗ ΚΑΙ ΚΑΤΑΣΚΕΥΗ ΕΞΥΠΝΟΥ ΣΠΙΤΙΟΥ

### 3.1 ΕΙΔΗ ΣΥΣΚΕΥΩΝ ΚΑΙ ΕΞΑΡΤΗΜΑΤΩΝ
Η νέα τεχνική ηλεκτρικών εγκαταστάσεων συνοδεύεται από μια μεγάλη ποικιλία νέων εξαρτημάτων και συσκευών.
Τα εξαρτήματα και οι συσκευές μπορούν να διαχωριστούν ανάλογα με τον τρόπο χρήσης τους σε κατηγορίες:
- Βασικά ή συστήματος
- Σύνθετες συσκευές
- Τηλεχειρισμού
- Παρελκόμενα
- Επικοινωνίας
- Αισθητήρες
- Ενδείξεων
- Μπουτόν
- Ελεγκτές
- Εισόδου
- Εξόδου

### 3.2 ΜΕΡΗ ΕΞΥΠΝΟΥ ΣΠΙΤΙΟΥ
Το έξυπνο σπίτι διαθέτει υπερσύγχρονο σύστημα ασφαλείας. Όχι μόνο ο συναγερμός, αλλά κι ένα ολοκληρωμένο σύστημα που αποτελείται από μοντέρνες κλειδαριές, μονωμένα παράθυρα και πόρτες ασφαλείας, όλα αυτά είναι η ραχοκοκαλιά της ασφάλειας του έξυπνου σπιτιού. Επιπλέον, δίνεται η δυνατότητα στον ιδιοκτήτη να παρακολουθεί τι συμβαίνει έξω από το σπίτι του με την βοήθεια καμερών.
Εκτός από όλα αυτά, το έξυπνο σπίτι είναι και οικολογικό. Ένα πολύ συχνό φαινόμενο είναι η εγκατάσταση φωτοβολταϊκών στην οροφή, αλλά και δίπλα από το σπίτι.
Με λίγα λόγια τα βασικότερα μέρη ενός έξυπνου σπιτιού είναι το σύστημα ασφαλείας και πρόσθετων εγκαταστάσεων τα οποία κάνουν την ζωή μέσα στο σπίτι πιο εύκολη, ασφαλή, οικολογική και κύριος άνετη!

## 4. Πρόταση κατασκευής

Κατασκευή ξύλινης μακέτας ενός έξυπνου σπιτιού το οποίο θα μπορεί να:

1. Ελέγχει τη θερμοκρασία του χώρου και να ανάβει τη θέρμανση
2. Ελέγχει την ενταση του φωτός και να ανοιγοκλείνει την τέντα
3. Χρησιμοποιεί αισθητήρα για έλεγχο της πόρτας ενεργοποιώντας τον συναγερμό
4. Να χρησιμοποιεί ηλιακή ενέργεια για την τροφοδοσία του
5. Να ελέγχει το φώτα εσωτερικού χώρου



[Αρχική Σελίδα έργου](https://github.com/legeonaf/robotics.ellak)

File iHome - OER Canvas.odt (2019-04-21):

iHome - OER PROJECT

Τίτλος: Κατασκευή έξυπνου σπιτιού στα πλαίσια του διαγωνισμού της ΕΛΛΑΚ 2018-19

Βαθμίδα: Γυμνάσιο

Στόχοι

Οι μαθητές/τριες θα πρέπει να είναι σε θέση να μπορούν να χειρίζονται χωρίς λάθη τα παρακάτω προγράμματα:

- inkscape για δημιουργία γραφικών (Ανοικτής άδειας χρήσης)
- Mblock (βασισμένο στο Scratch) για την δημιουργία του κώδικα (Ανοικτής άδειας χρήσης)
- Notepad++ ή atom (MIT License) για την συγγραφή των αρχείων md στο github
- Gimp για επεξεργασία των φωτογραφιών και των εικόνων που απαιτούνται
- Γραμμή εντολών για διαχείριση του υλικού τους και χρήση του git

Θα πρέπει να μπορούν να χρησιμοποιούν απλά ηλεκτρολογικά και ξυλουργικά εργαλεία με ασφάλεια όπως κατσαβίδια κλπ

Οργάνωση Project

Πότε/Στάδια υλοποίησης | Τί | Εργαλείο | Ποιος
1 | Σχεδιασμός σπιτιού | Πρόγραμμα Διανυσματικών γραφικών inkscape (https://inkscape.org/)
2 | Εύρεση Υλικών – Ξυλείας – Κατασκευή ξυλοκατασκευής | Εργαλεία ξυλουργικής, μπογιές Εργαστήριο Τεχνολογίας
3 | Τοποθέτηση καλωδιώσεων | utp καλώδια, πολύμετρο για έλεγχο, απογυμνωτής, Πιστόλι θερμοκόλλησης
4 | Τοποθέτηση ηλεκτρονικού εξοπλισμού (Arduino, κλπ) | Κατσαβίδια, Θερμοκόλληση,
5 | Κατασκευή εσωτερικού διάκοσμου | Εργαλεία ξυλουργικής, μπογιές Εργαστήριο Τεχνολογίας
6 | Προγραμματισμός | Mblock
7 | Έλεγχος λειτουργίας
8 | Δημιουργία github | Editor notepad++ ή atom
9 | Δημιουργία βίντεο | Πρόγραμμα επεξεργασίας βίντεο
10 | Τελικός έλεγχος και ανέβασμα υλικών

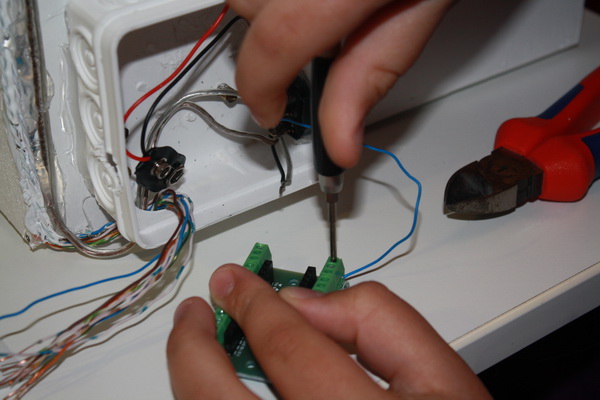
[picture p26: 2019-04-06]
photos/IMG_0261_resize.JPG

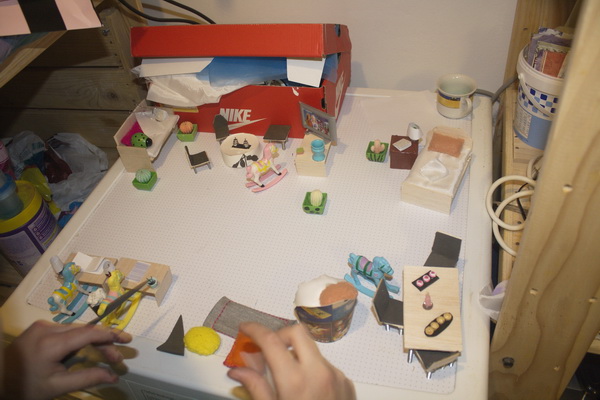
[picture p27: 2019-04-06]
photos/_MG_0189_resize.jpg

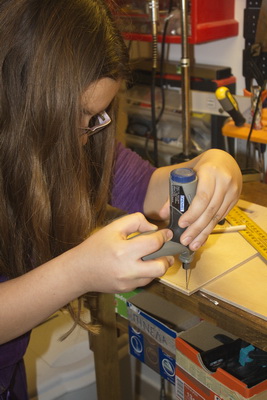
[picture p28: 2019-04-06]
photos/_MG_0086_resize.jpg

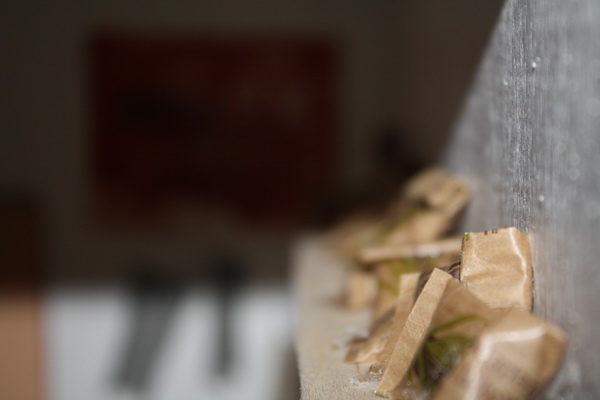
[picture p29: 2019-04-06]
photos/IMG_0279_resize.JPG

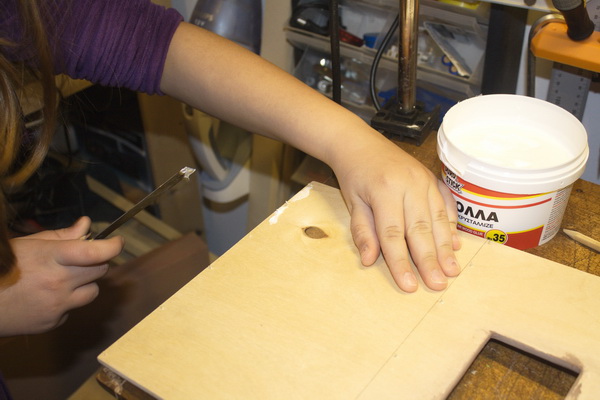
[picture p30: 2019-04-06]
photos/_MG_0112_resize.jpg

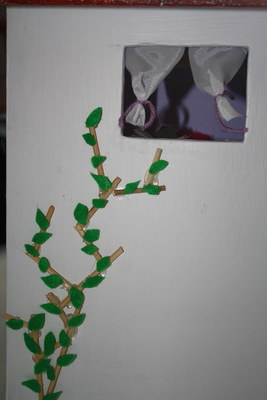
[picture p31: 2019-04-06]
photos/IMG_0289_resize.JPG

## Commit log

2018-12-06 Νέο readme
2019-04-06 Εξυπνο Σπίτι εκδοση 1
2019-04-21 Γεωργία Λέων final steps
    [Switch.fzz]
2019-05-07 Georgia Αλλαγή ονομάτων αρχείων σε φωτογραφίες
